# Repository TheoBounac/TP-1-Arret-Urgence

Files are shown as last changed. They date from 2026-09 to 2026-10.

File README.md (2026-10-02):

 <p align="center">
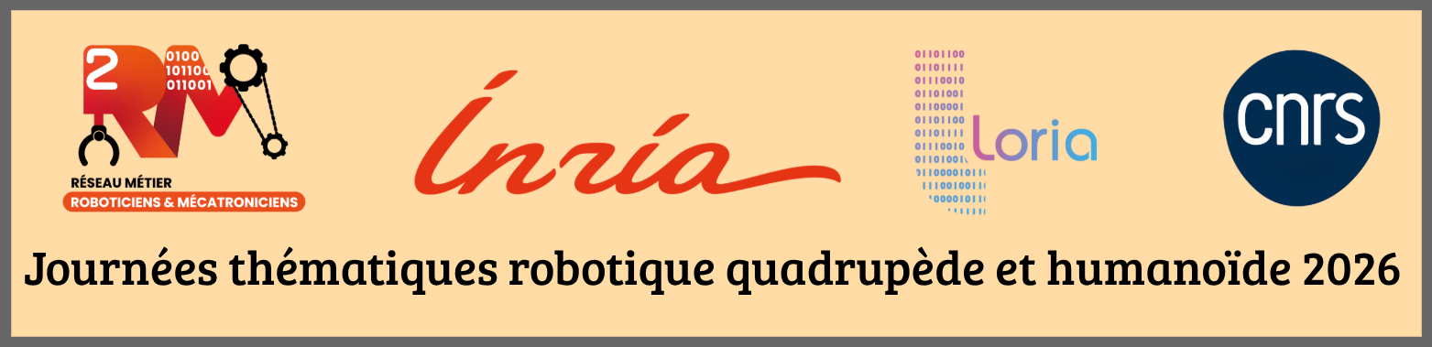
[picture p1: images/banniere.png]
  
  <br>
 </p>
 
 <div align="justify">
Le réseau métier des roboticiens et mécatroniciens du CNRS organise des journées thématiques sur les robots quadrupèdes et humanoïdes afin de favoriser le partage de connaissances et les retours d’expérience autour de ces robots. Cette journée est cofinancée par le réseau 2RM et INRIA. [12 et 13 octobre 2026] 
</div>

 ---
 
# TP1 — Arrêt d’urgence sans fil pour robots Unitree Go2/G1

 <p align="center">
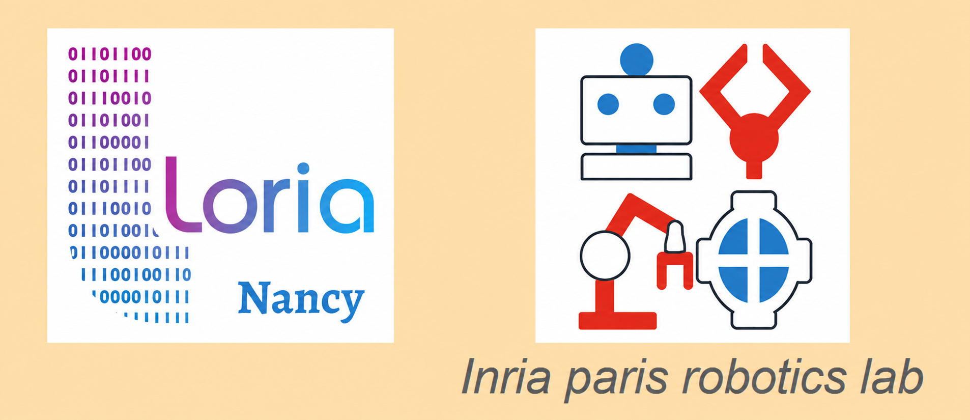
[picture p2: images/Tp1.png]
  
  <br>
 </p>

Ce TP est le premier TP des journées thématiques *robotique quadrupède et humanoïde 2026*. Cet arrêt d’urgence se base sur le travail réalisé par le laboratoire Inria Paris, équipe Willow: [https://github.com/inria-paris-robotics-lab/wireless-e-stop/tree/master](https://github.com/inria-paris-robotics-lab/wireless-e-stop/tree/master).

Ce TP a pour objectif de comprendre, assembler et tester un prototype d’arrêt d’urgence sans fil pour robots Unitree Go2 et G1.

## 📑 Sommaire

1. [Principe de fonctionnement du système](#principe)
2. [Matériel nécessaire](#composants)
3. [Montage de l'Emetteur](#transmetteur)
4. [Montage du Récepteur](#recepteurvrai)
5. [Fonctionnement logique](#logique)
6. [Test avec une LED](#test-led)
7. [Test sur le robot](#test-robot)

---

## 1. Principe de fonctionnement du système

 <div align="justify">
Sur la carte mère des robots Unitree Go2 et G1, deux broches portent le nom `STOP`. Lorsque ces deux broches sont reliées électriquement en circuit fermé, le robot coupe l’alimentation des moteurs et passe en état d’arrêt d’urgence, généralement signalé par des LEDs rouges.
</div>

 <p align="center">
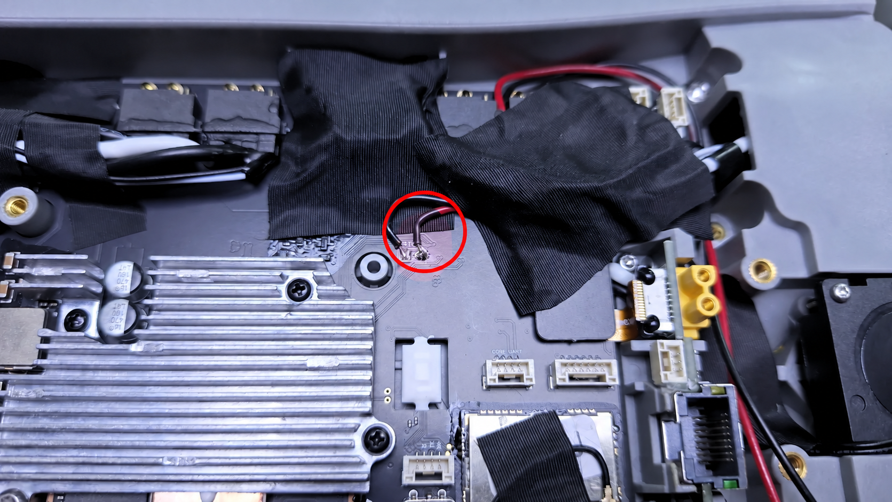
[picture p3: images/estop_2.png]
  
  <br>
  <em>Pin Stop sur la carte mère du Go2</em>
 </p>

Le système proposé repose sur deux groupes de composants :

- un **émetteur** côté opérateur 
- un **récepteur** côté robot.

 <div align="justify">
L’émetteur reste à proximité de l’opérateur. Lorsque l’opérateur appuie sur le bouton d’arrêt d’urgence, l'information est envoyée par radiofréquence au récepteur.
Le récepteur est accroché au robot et relié aux deux broches `STOP` de la carte mère par un relais, qui ferme le circuit en cas d'arrêt d'urgence qui coupe alors l'alimentation des moteurs du robot.
</div>

Schéma global :

 <p align="center">
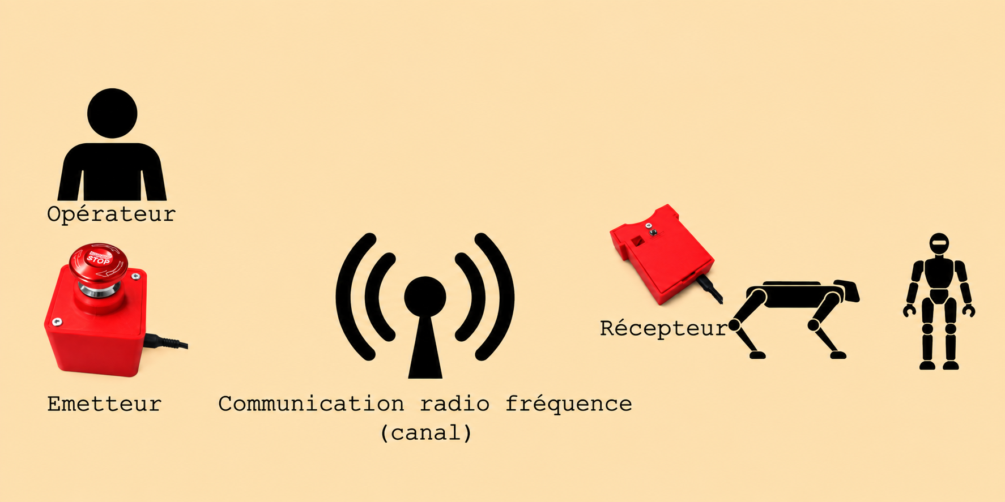
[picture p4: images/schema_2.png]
  
  <br>
 </p>

---

## 2. Matériel nécessaire

 <p align="center">
 <kbd>
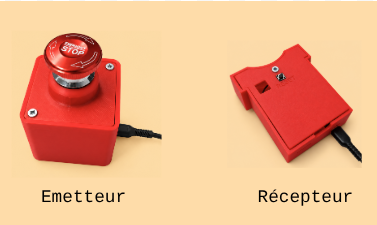
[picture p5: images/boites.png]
  
</kbd>
</p>
Tout le matériel est fourni le jour du TP.

### Emetteur
 <p align="center">
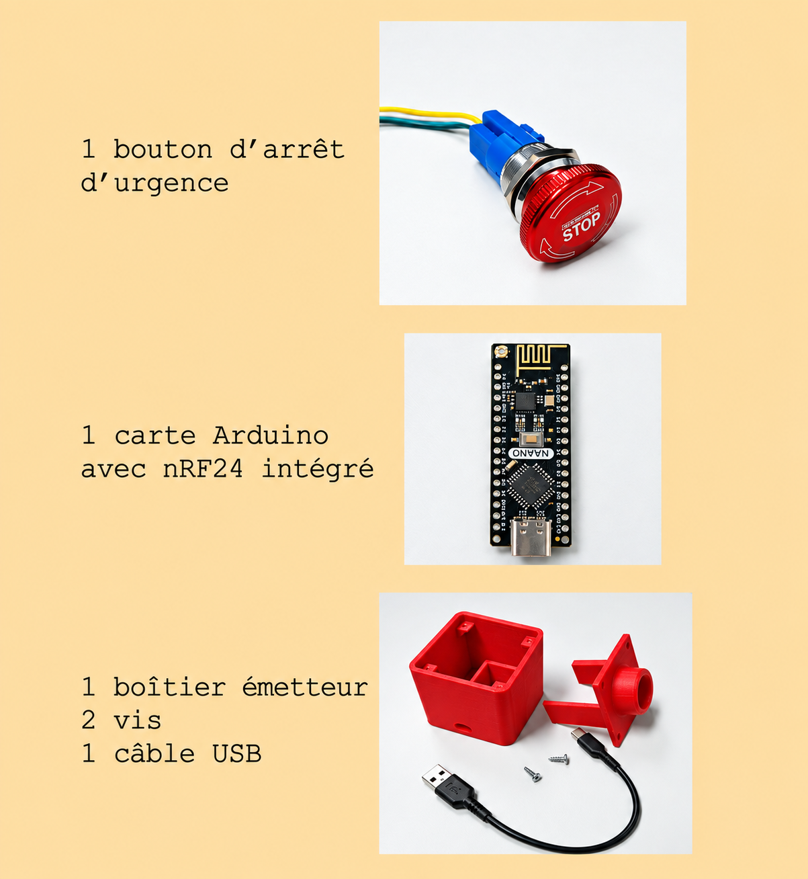
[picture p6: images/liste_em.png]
  
  <br>
 </p>

 ### Récepteur
 <p align="center">
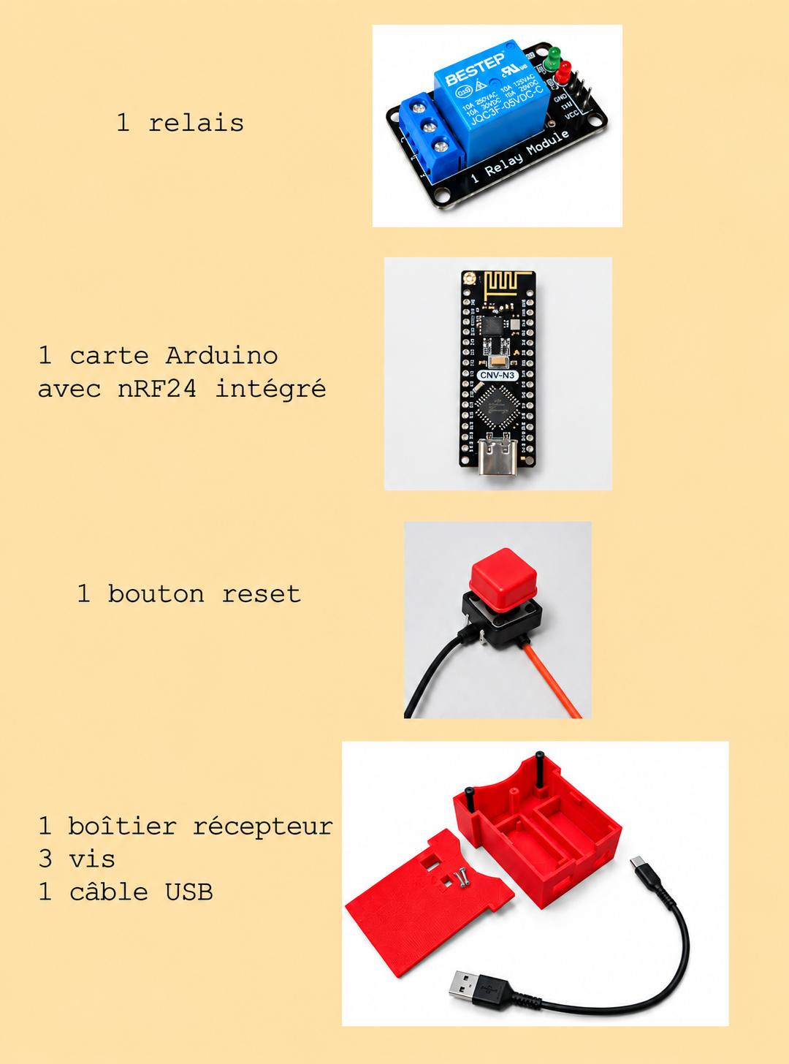
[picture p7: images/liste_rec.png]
  
  <br>
 </p>

---

## 3. Montage de l'Emetteur

<table align="center">
  <tr>
    <th>Carte Arduino</th>
  </tr>
  <tr>
    <td align="center">
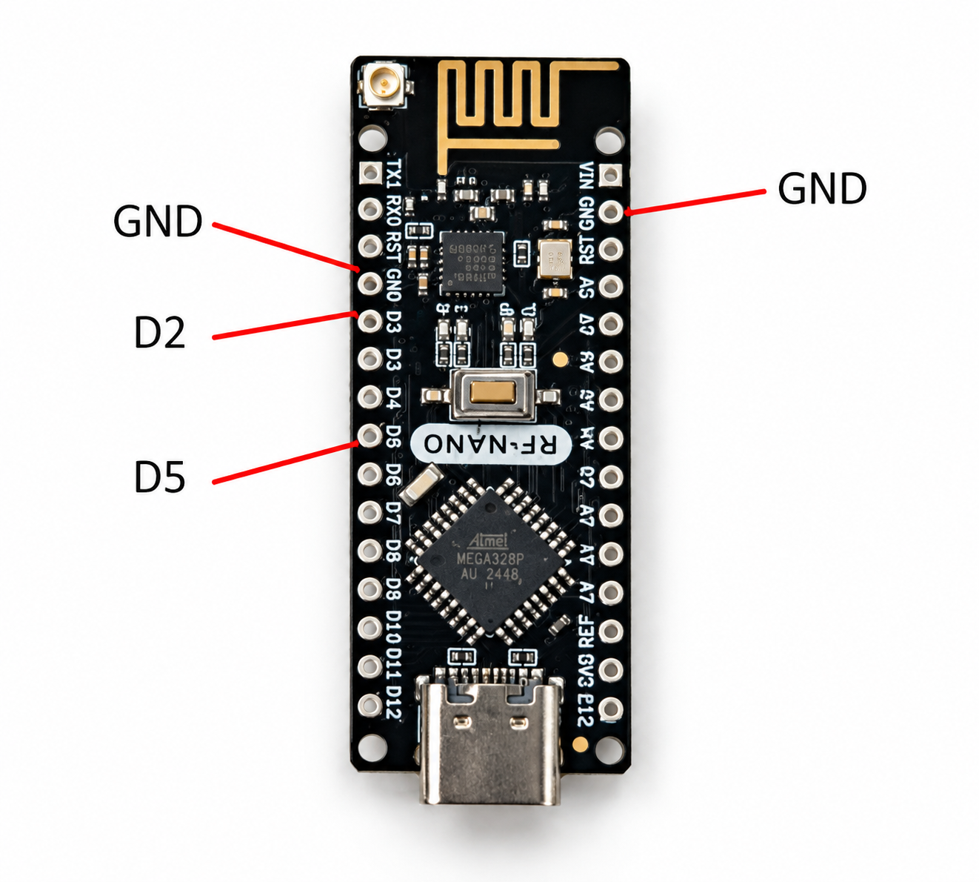
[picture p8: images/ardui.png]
Carte Arduino
      
    </td>
  </tr>
</table>

<div align="center">
<table>
  <tr>
    <th>STOP button</th>
    <th>Carte Arduino</th>
    <td rowspan="3">
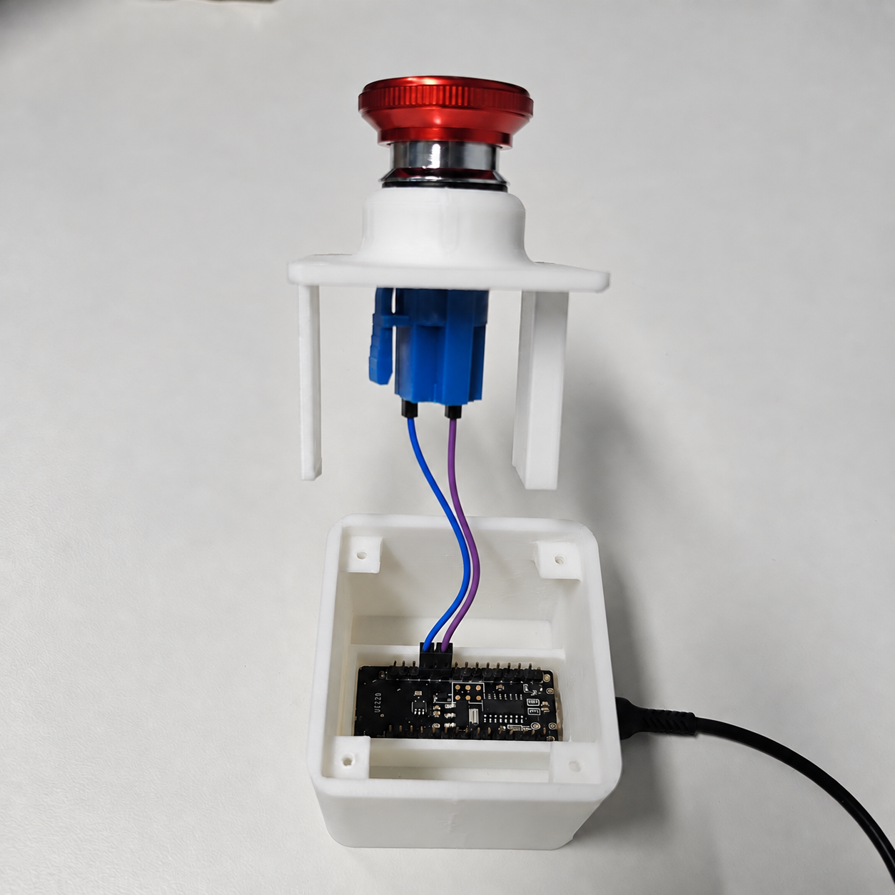
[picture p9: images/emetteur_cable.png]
Montage transmitter
      
    </td>
  </tr>

  <tr>
    <td>C / COM</td>
    <td>GND</td>
  </tr>

  <tr>
    <td>NC</td>
    <td>D2</td>
  </tr>
</table>
</div>
 
---

## 4. Montage du Récepteur

### Relais

<table align="center">
  <tr>
    <th>Relais</th>
    <th>Carte Arduino</th>
    <td rowspan="4">
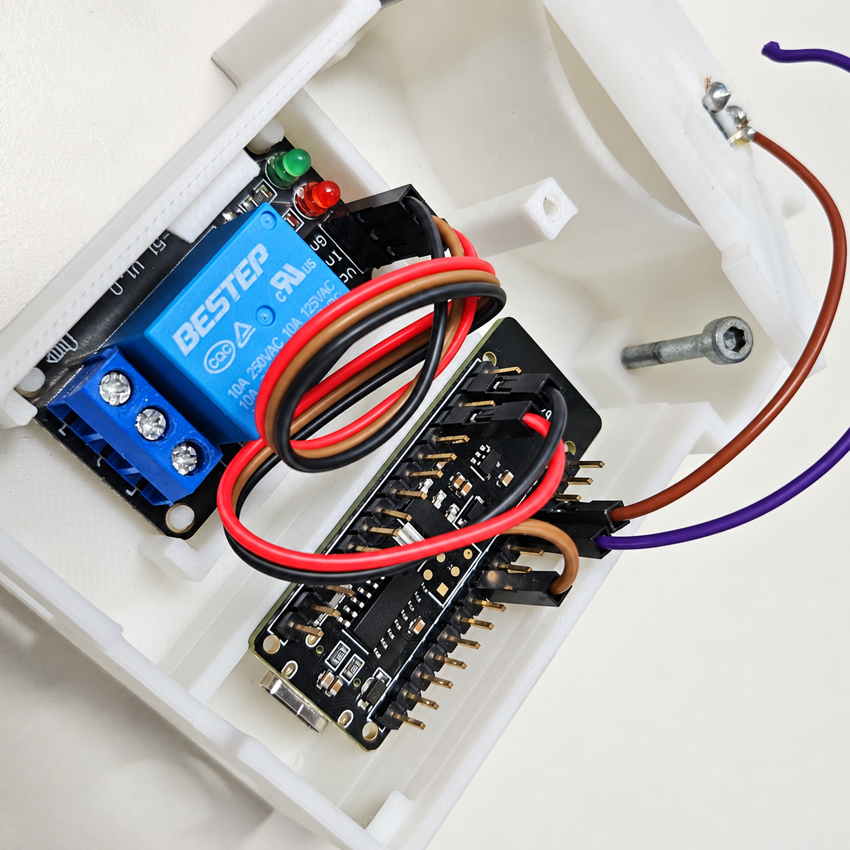
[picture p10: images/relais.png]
Montage relais
      
    </td>
  </tr>
  <tr>
    <td>VCC</td>
    <td>5V</td>
  </tr>
  <tr>
    <td>IN1</td>
    <td>D5</td>
  </tr>
  <tr>
    <td>GND</td>
    <td>GND</td>
  </tr>
</table>

### Bouton reset

<table align="center">
  <tr>
    <th>Reset button</th>
    <th>Carte Arduino</th>
    <td rowspan="3">
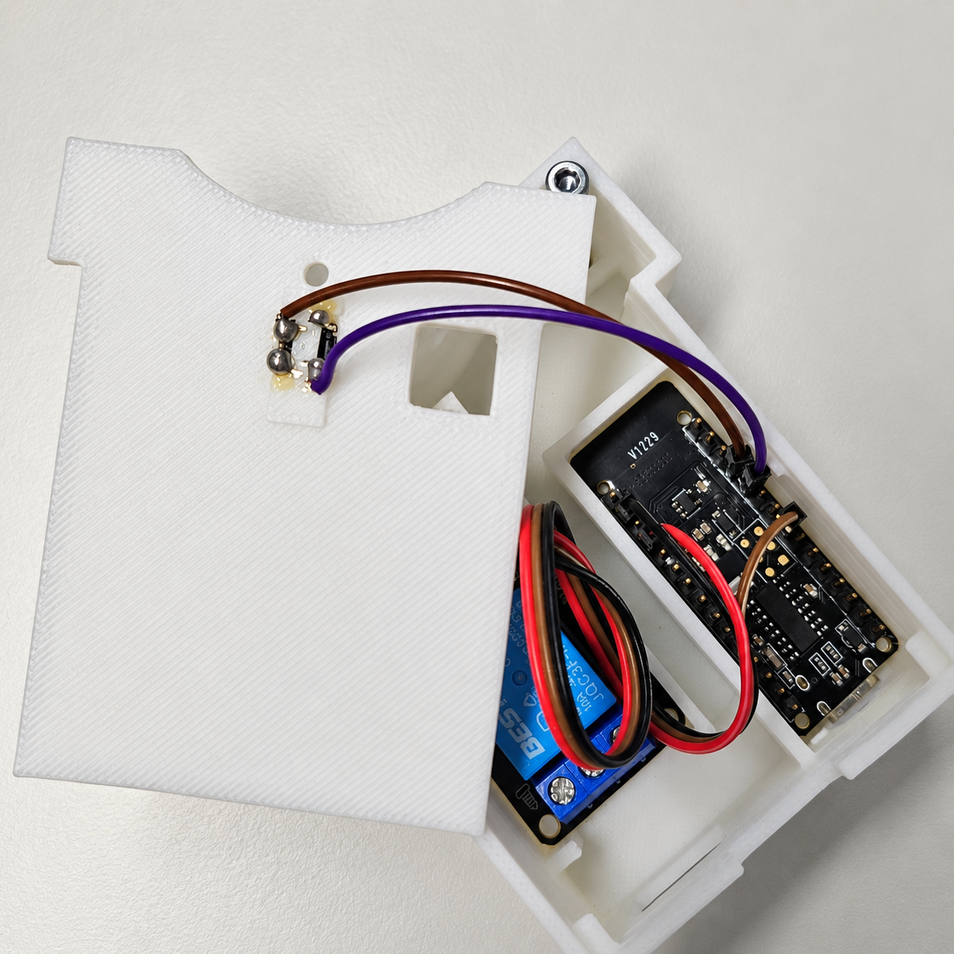
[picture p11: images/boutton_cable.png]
Montage bouton reset
      
    </td>
  </tr>
  <tr>
    <td>Pin 1</td>
    <td>D2</td>
  </tr>
  <tr>
    <td>Pin 2</td>
    <td>GND</td>
  </tr>
</table>

---
  
## 5. Fonctionnement logique

### Emetteur — `emetteur.ino`

L'émetteur :

- lit l’état du bouton d’arrêt d’urgence 
- convertit cet état en booléen 
- envoie ce booléen par radio toutes les 100 ms

### Récepteur — `recepteur.ino`

Le récepteur :

- écoute les messages radio envoyés par l'émetteur 
- utilise un algorithme de type **leaky bucket** pour détecter une perte de communication 
- commande le relais connecté aux broches `STOP` du robot

 ### Le relais ferme le circuit `STOP` dans les cas suivants :

- CAS 1: un message `TRUE` est reçu de l'émetteur 
- CAS 2: aucun message n’est reçu pendant une certaine période 
- CAS 3: l’alimentation du récepteur est coupée. Car le relais est en **normalement fermé**, c’est-à-dire que si l’alimentation du récepteur est coupée, le relais revient naturellement dans l’état qui déclenche l’arrêt d’urgence.
  
 <p align="center">
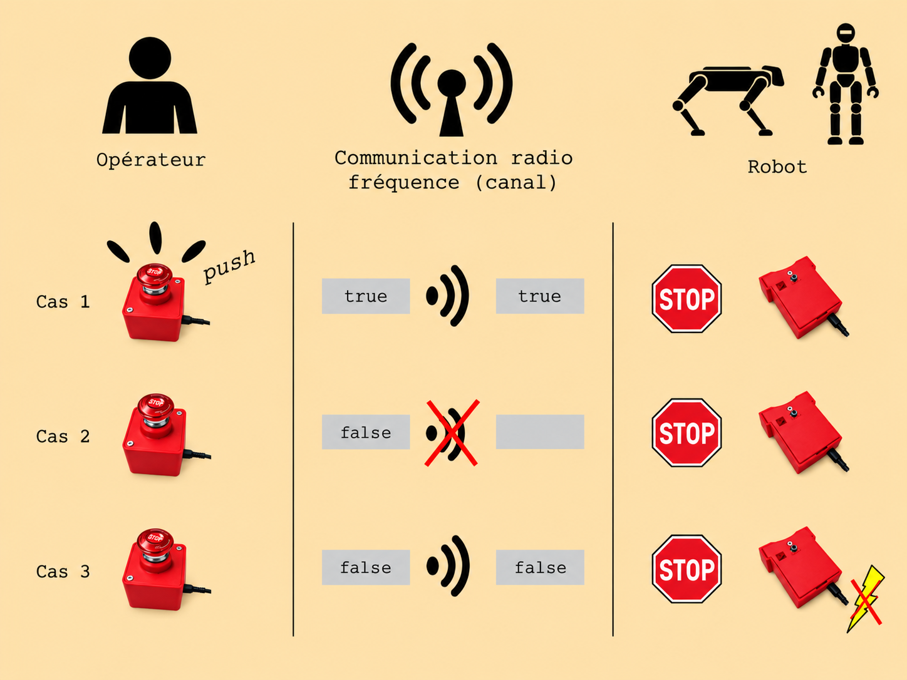
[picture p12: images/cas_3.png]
  
  <br>
 </p>

> ⚠️ **Attention**
>
> Lorsque le récepteur est alimenté, il place le relais en **circuit ouvert**, s'il n'est pas assez rapide pour effectuer cette action il peut au démarrage déclencher l'arrêt d'urgence.
> 
Après un arrêt d’urgence, si le receiver reste alimenté (par une batterie externe), le système doit être réarmé manuellement en maintenant le bouton reset pendant 3 secondes.

---

## 6. Test avec LED

Branchez la sortie du relais en circuit fermé avec la LED, comme indiqué sur la photo suivante :

 <p align="center">
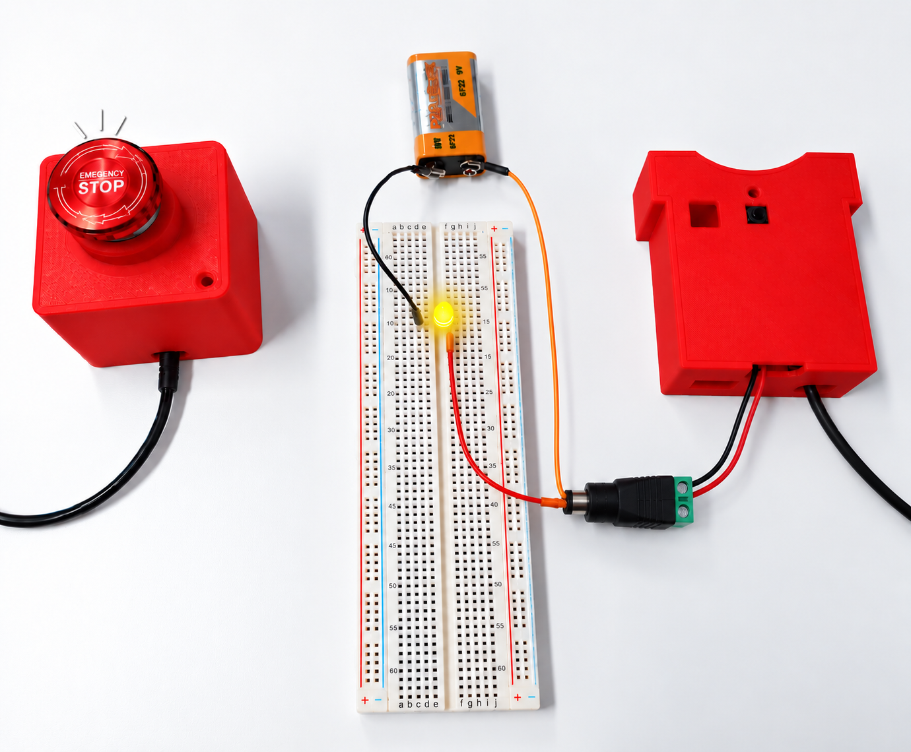
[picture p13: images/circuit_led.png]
  
  <br>
 </p>

Dans ce test :

```text
LED Jaune éteinte  → circuit ouvert → robot autorisé
LED Jaune allumée  → circuit fermé  → arrêt d’urgence activé, le robot est arrêté
```

Il est aussi possible de s’aider de la LED intégrée au module relais.

 <p align="center">
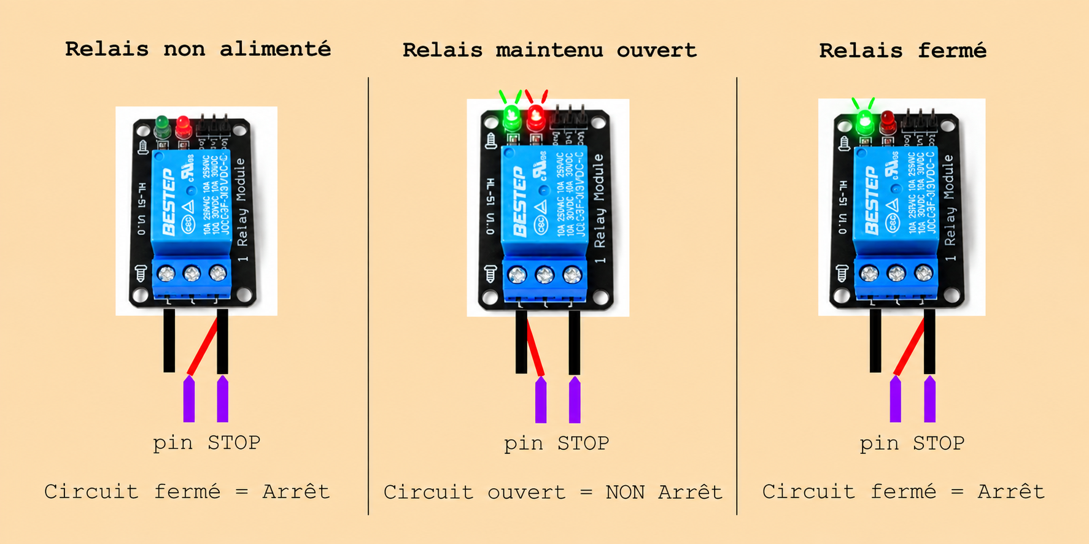
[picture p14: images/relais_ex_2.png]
  
  <br>
 </p>

---

## 7. Test sur robot

---

## 👥 Authors & Contributors

**Author:**  
Louise Manson, Timothee CARECCHIO, Laboratory **Inria Paris**

Théo Bounaceur, Laboratory **LORIA** CNRS

🧬 Field: Unitree robots · Emergency STOP 

📫 Contact: theo.bounaceur@loria.fr & louise.manson@inria.fr & timothee.carecchio@inria.fr

**Supervisors / Advisors:**  
- Pierre-guillaume Raverdy, Ingénieur robotique, Inria Paris
- Adrien Guenard, Ingénieur robotique, Loria

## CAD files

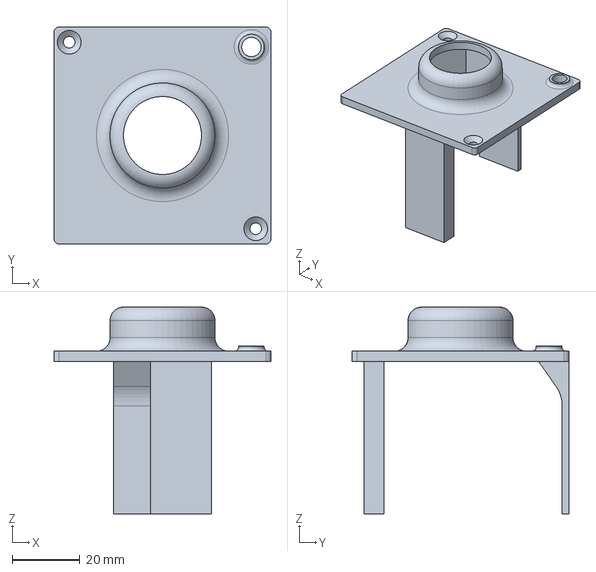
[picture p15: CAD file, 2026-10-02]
hardware/CAD/TransmitterTop_V2.FCStd
64.0 x 64.0 x 61.0 mm

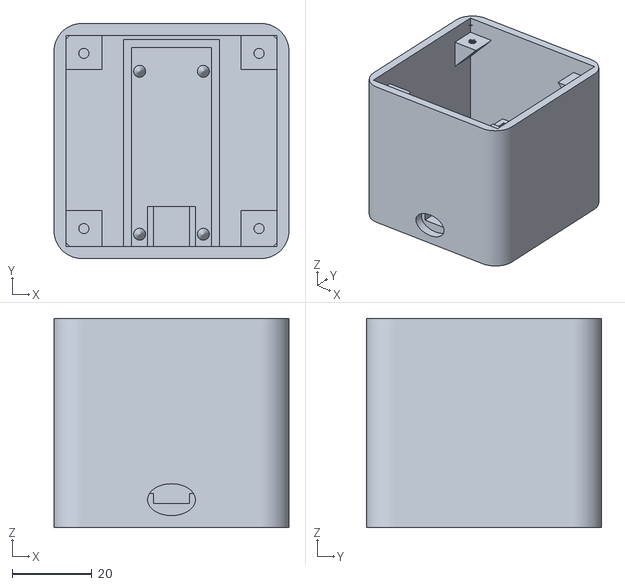
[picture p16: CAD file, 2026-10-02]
hardware/CAD/Transmitter-Corps.stl
59.0 x 59.0 x 52.5

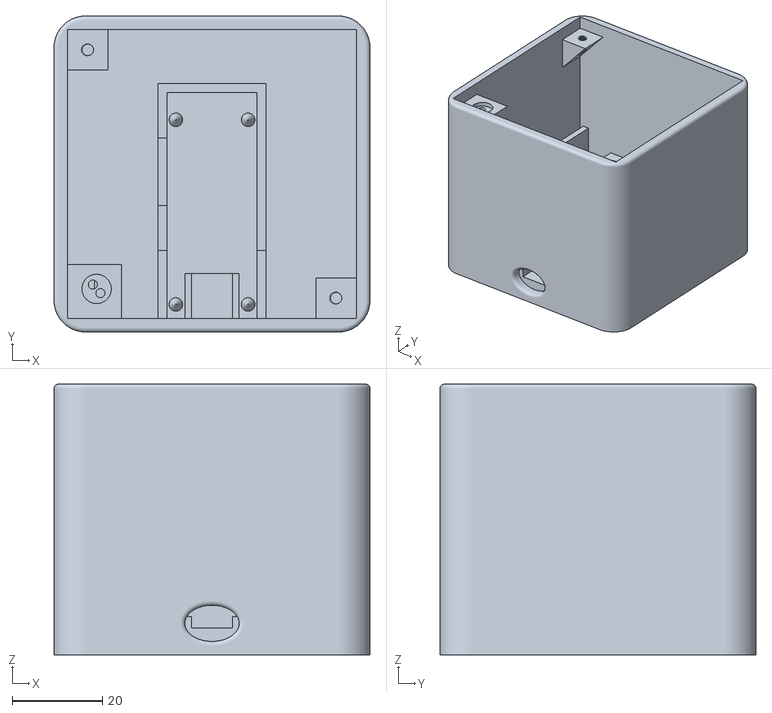
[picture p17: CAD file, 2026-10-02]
hardware/CAD/Transmitter_V4-Body.stl
70.0 x 70.0 x 60.0

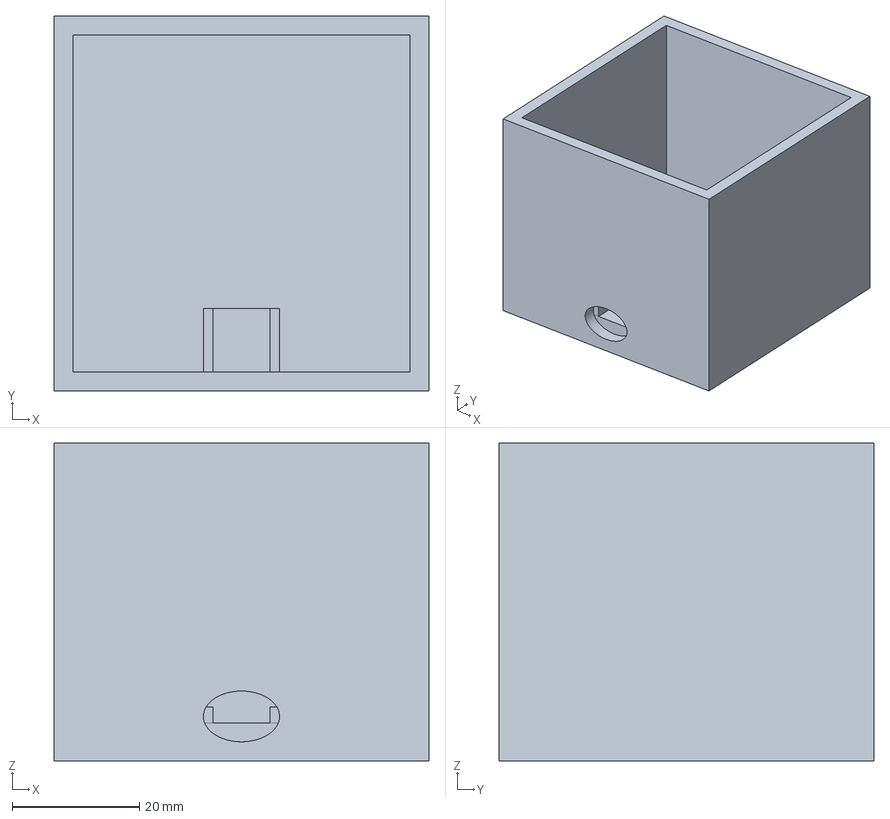
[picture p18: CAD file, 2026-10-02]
hardware/CAD/Transmitter.FCStd
59.0 x 59.0 x 50.0 mm

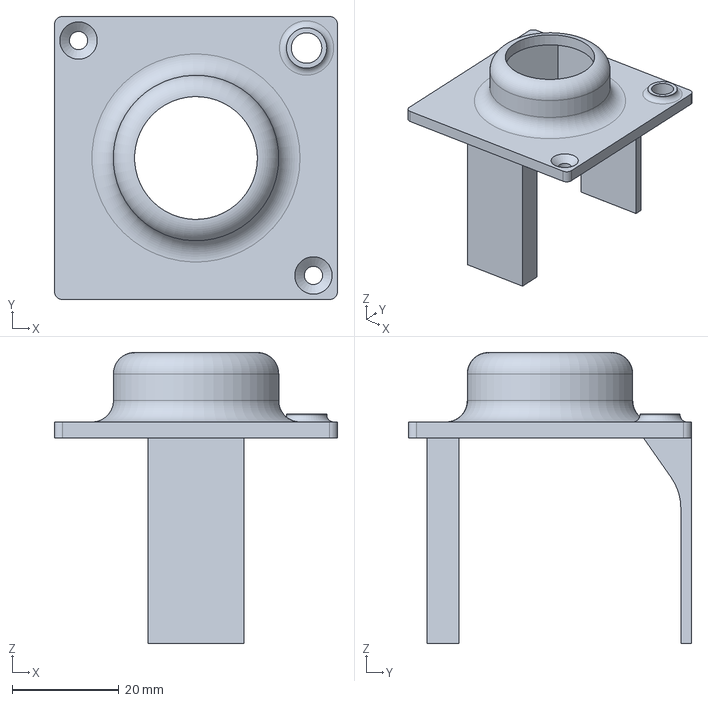
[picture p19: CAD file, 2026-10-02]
hardware/CAD/TransmitterTop.FCStd
53.0 x 53.0 x 54.5 mm

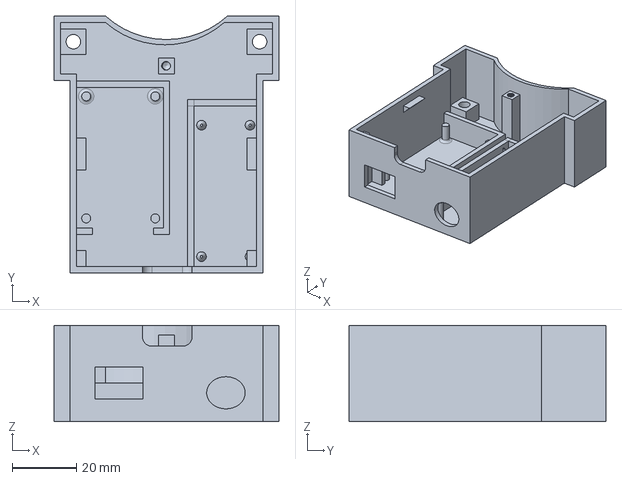
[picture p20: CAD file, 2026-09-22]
hardware/CAD/Receiver.FCStd
70.0 x 80.0 x 30.0 mm

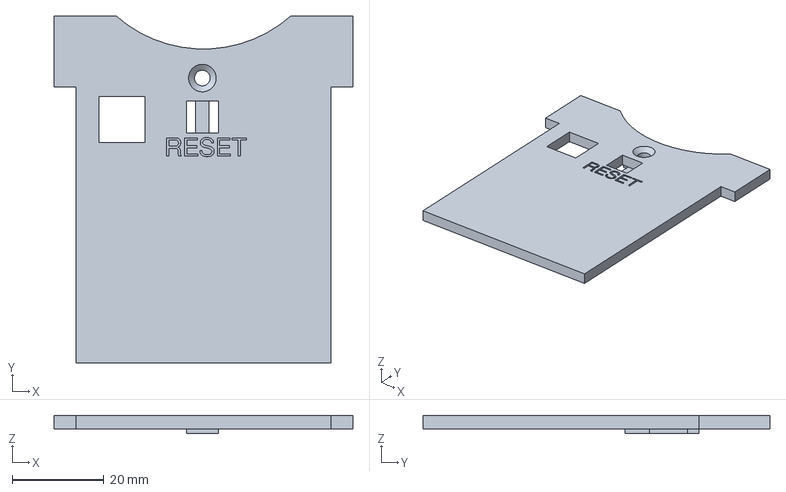
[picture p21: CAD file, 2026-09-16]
hardware/CAD/ReceiverTop.FCStd
65.0 x 75.5 x 4.00 mm

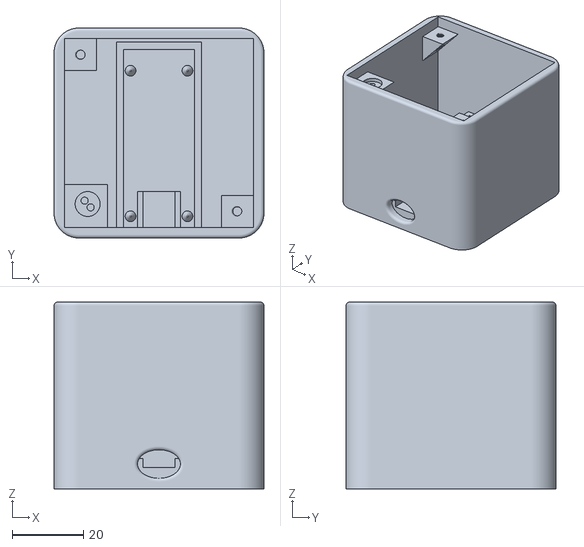
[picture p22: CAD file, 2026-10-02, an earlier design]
hardware/CAD/Transmitter_V2-Body.stl
59.0 x 59.0 x 52.5

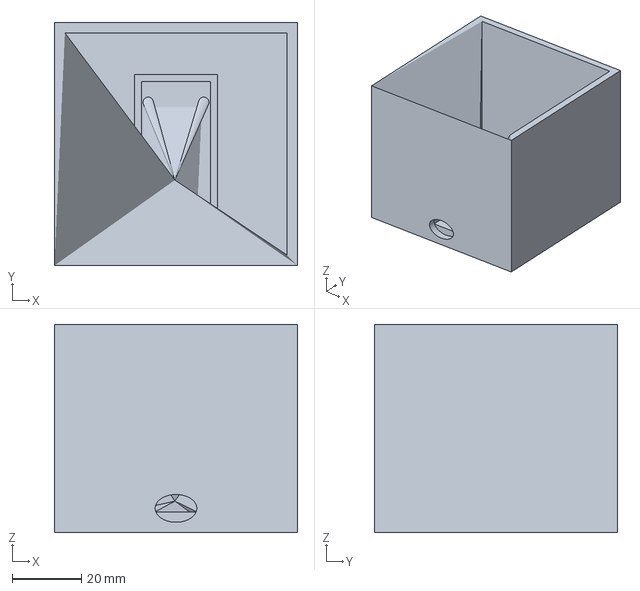
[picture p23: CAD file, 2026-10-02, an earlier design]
hardware/CAD/Transmitter_V3.FCStd
70.0 x 70.0 x 60.0 mm

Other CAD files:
hardware/CAD/Transmitter (copy).FCStd
hardware/CAD/Transmitter_V4.FCStd
hardware/CAD/TransmitterTop-Body.stl
hardware/CAD/TransmitterTop_V2-Body.stl
hardware/CAD/Transmitter_V2.FCStd

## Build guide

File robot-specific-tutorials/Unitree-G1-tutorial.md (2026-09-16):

Wiring tutorial on Unitree G1
===
> [!IMPORTANT]
> Remove the battery from the robot before opening it.

Lay the robot on its front so that you can access the screws in the back.   
Unscrew the two screws of the handle.   

<div align="center">
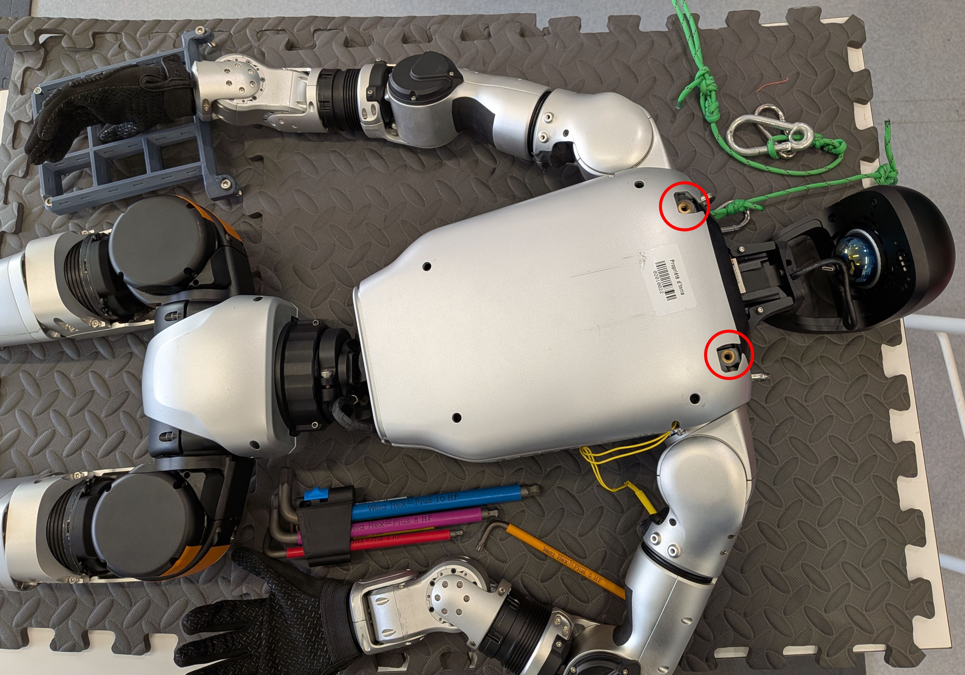
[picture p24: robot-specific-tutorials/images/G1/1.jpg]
Robot on its back with the 2 screws to remove marked in red

</div>
<br>

With a plastic card pop open the plastic outer shell. The clips that needs to be pushed are marked in red in the following pictures, be careful to also remove the one on top of the shoulder.   

<table>
    <td>
        <div align="center">
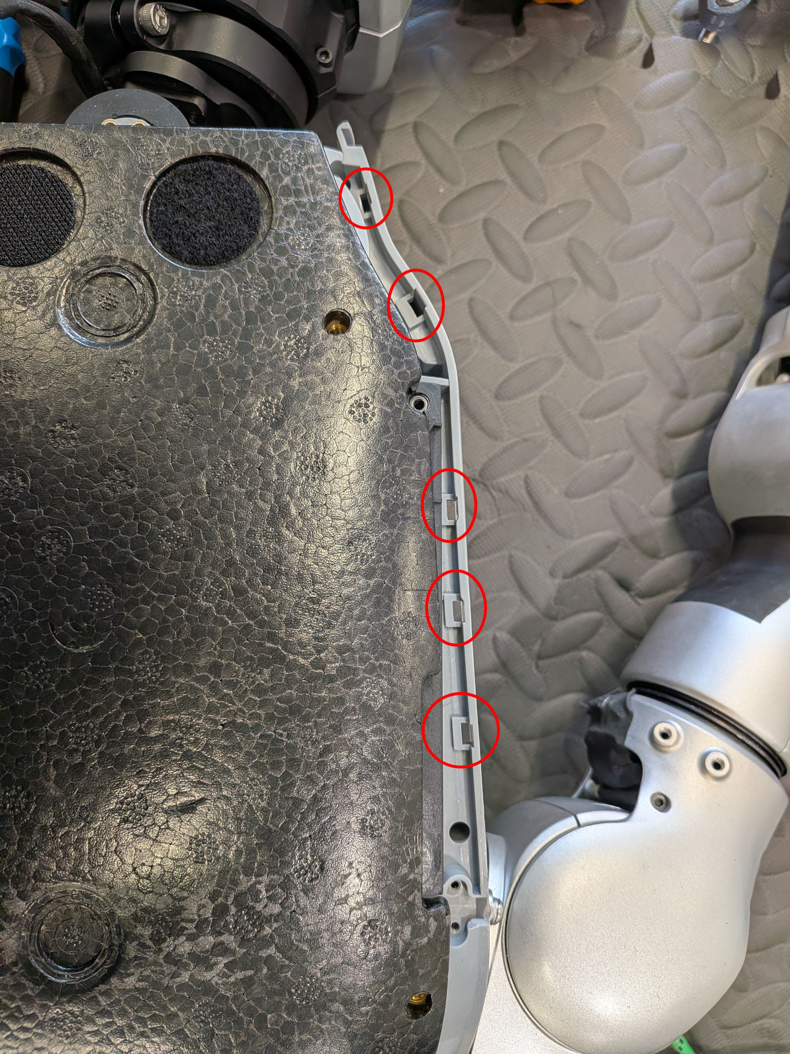
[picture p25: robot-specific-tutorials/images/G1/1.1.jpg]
            
        </div>
    </td>
        <td>
        <div align="center">
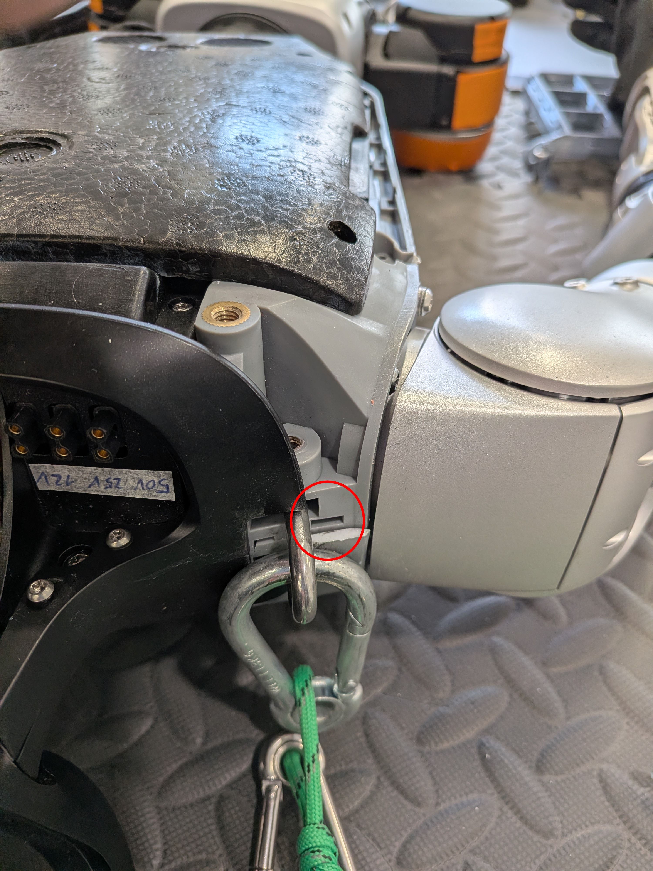
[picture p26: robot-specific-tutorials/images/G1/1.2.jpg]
            
        </div>
    </td>
</table>
<br>

Next to remove the polyester pannel unscrew the 4 screws marked in red and carefully pull. The bottom part of the pannel (where there are two velcro pads) is double taped, use a plastic card to carefuly unstick it and pull off the pannel entirely.  

<div align="center">
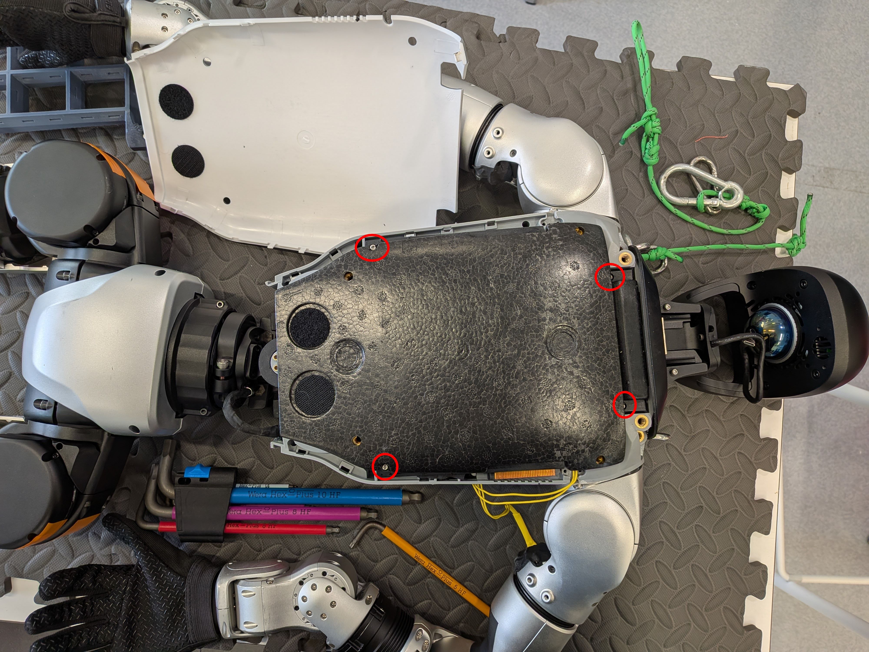
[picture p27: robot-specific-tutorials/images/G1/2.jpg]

</div>
<br>

The emergency stop plug is dead-center (in red).   
<div align="center">
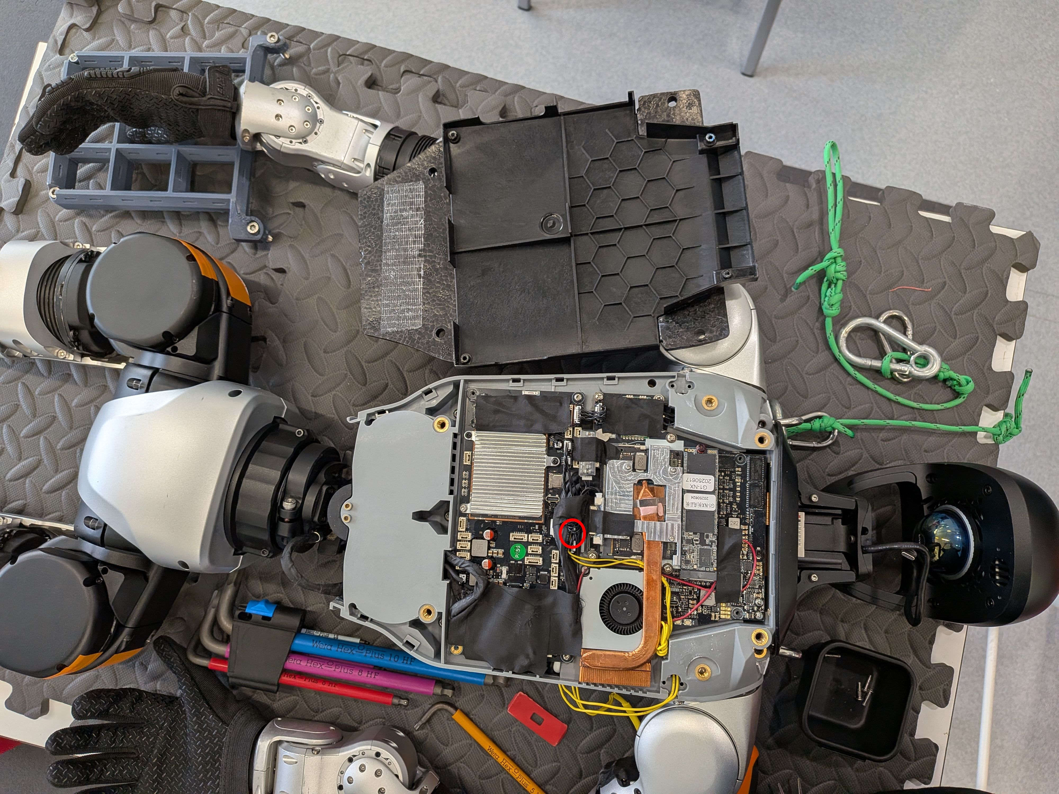
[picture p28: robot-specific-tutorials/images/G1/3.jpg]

</div>
<br>

You will need to wire 2 wires to a GH 1.25 mm 2 pin male connector.  Keep the other end of the wires unsoldered so that you can thread them under the caloduc and through the vent to the outside the robot.
<table>
    <td>
        <div align="center">
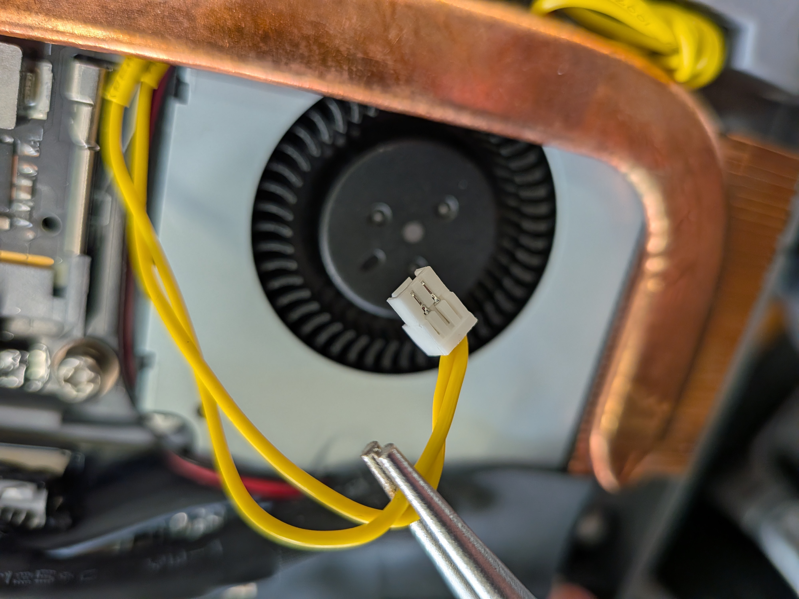
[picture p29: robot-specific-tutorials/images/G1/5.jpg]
            
        </div>
    </td>
        <td>
        <div align="center">
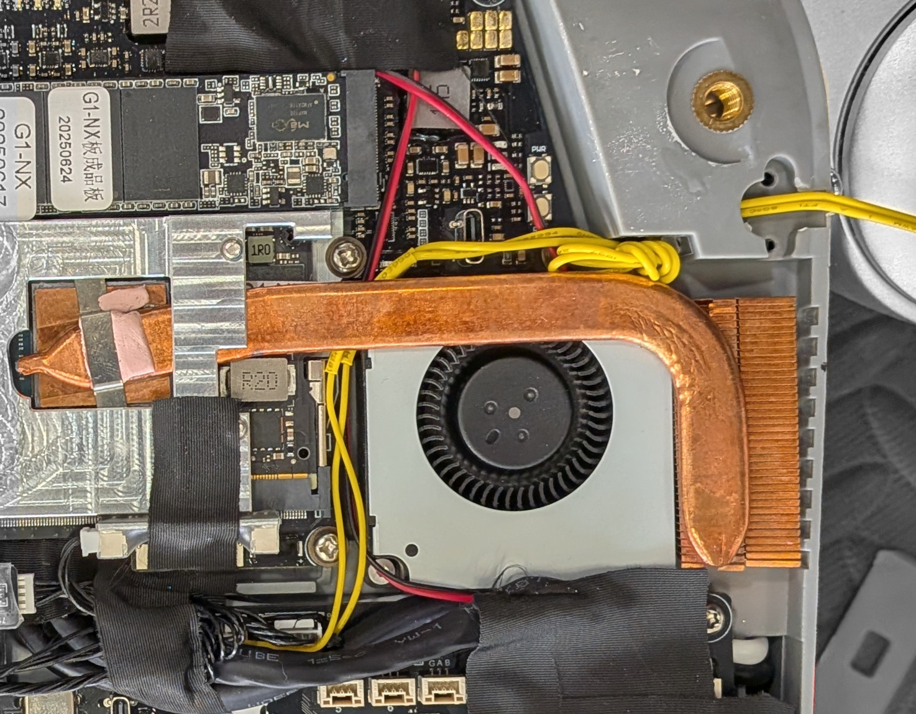
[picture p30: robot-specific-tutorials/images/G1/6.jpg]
            
        </div>
    </td>
</table>
<br>

You can connect the other end of the wire (the part that will be outside of the robot) directly to the receiver module or to any connector of your liking.  
We use a female 5.5 x 2.1mm Power Jack connector plugged to a male connector of the same type soldered to the receiver :
<div align="center">
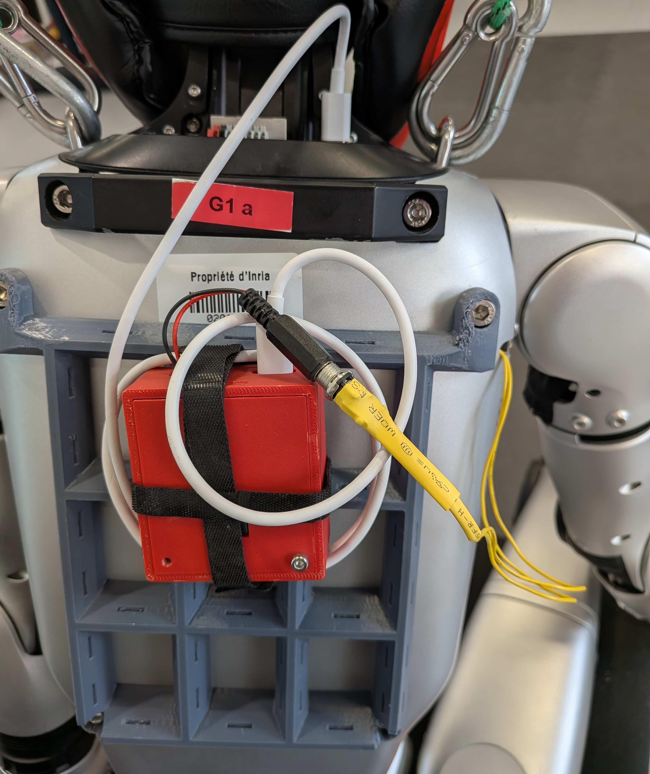
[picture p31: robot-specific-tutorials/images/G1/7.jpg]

</div>
<br>   

The "backpack" can be found in our [CAD-parts repository](https://github.com/inria-paris-robotics-lab/CAD-parts/).

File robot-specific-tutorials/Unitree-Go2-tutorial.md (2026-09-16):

Wiring tutorial on Unitree Go2
===
> [!IMPORTANT]
> Remove the battery from the robot before opening it.

Unscrew the two screws of the handle.   

<div align="center">
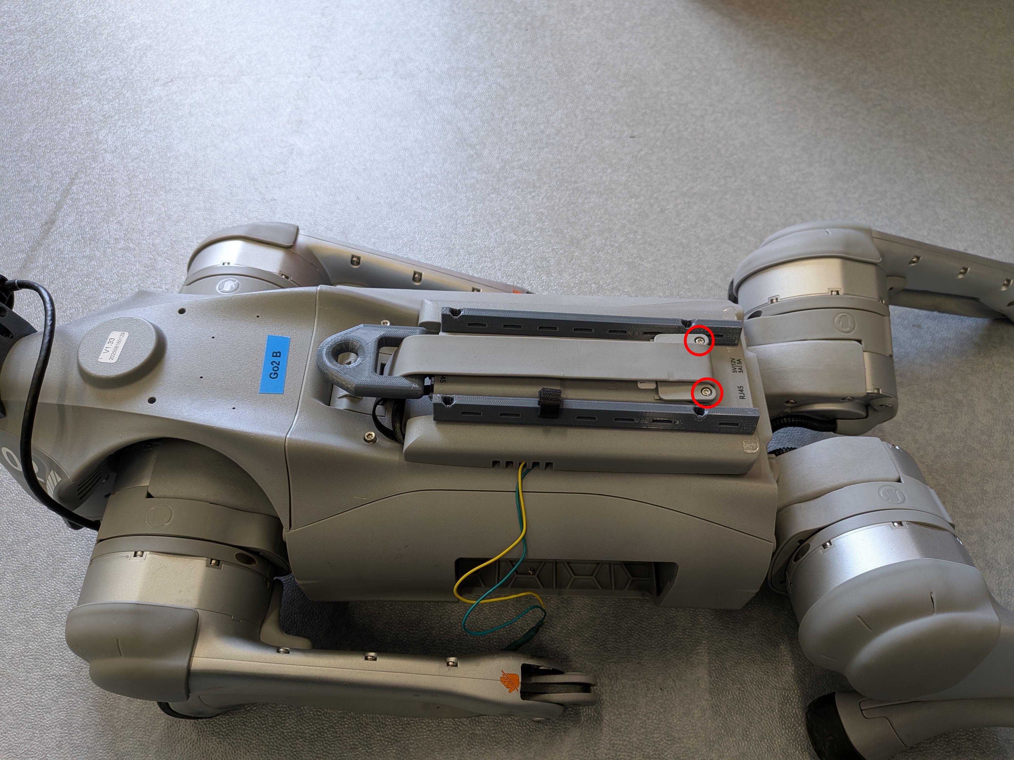
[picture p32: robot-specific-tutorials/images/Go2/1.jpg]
The 2 screws of the handle marked in red

</div>
<br>

Remove the 4 screws that holds the Jetson.

<div align="center">
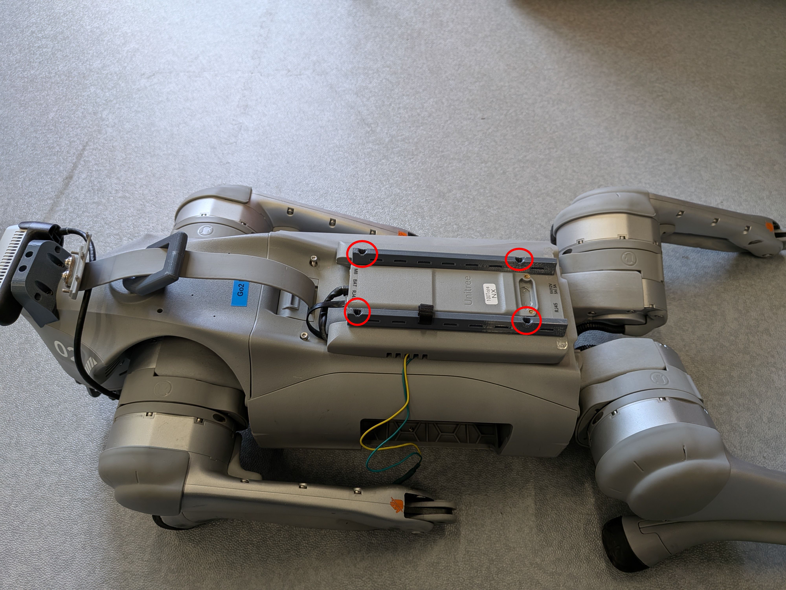
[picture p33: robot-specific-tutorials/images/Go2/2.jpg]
The 4 screws of the jetson marked in red

</div>
<br>

Next, unplug the power and ethernet wire connecting the robot to the Jetson and put the Jetson aside.   
<div align="center">
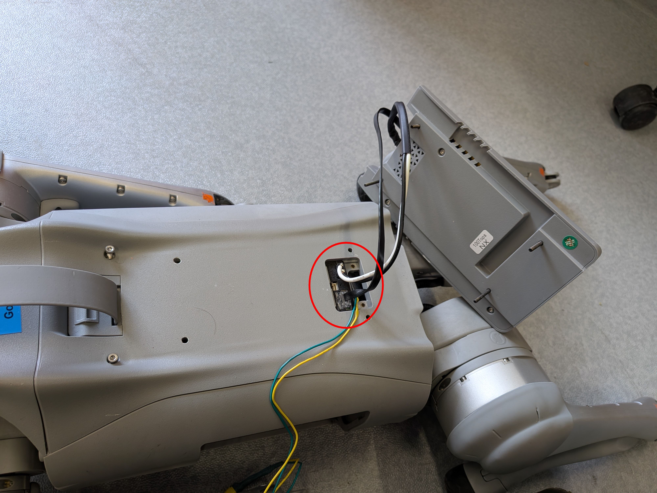
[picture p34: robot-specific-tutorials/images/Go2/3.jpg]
The wires to unplug marked in red

</div>
<br>

To remove the top plastic shell of the robot and access the mother board, remove 4 screws: two on the top and two on the back, near the legs actuators.    
<table>
    <td>
        <div align="center">
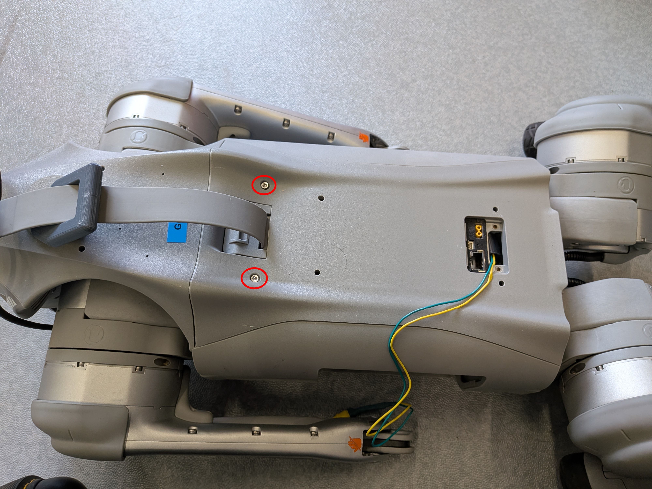
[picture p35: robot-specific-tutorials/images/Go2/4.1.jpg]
Localisation of the top screws
            
        </div>
    </td>
        <td>
        <div align="center">
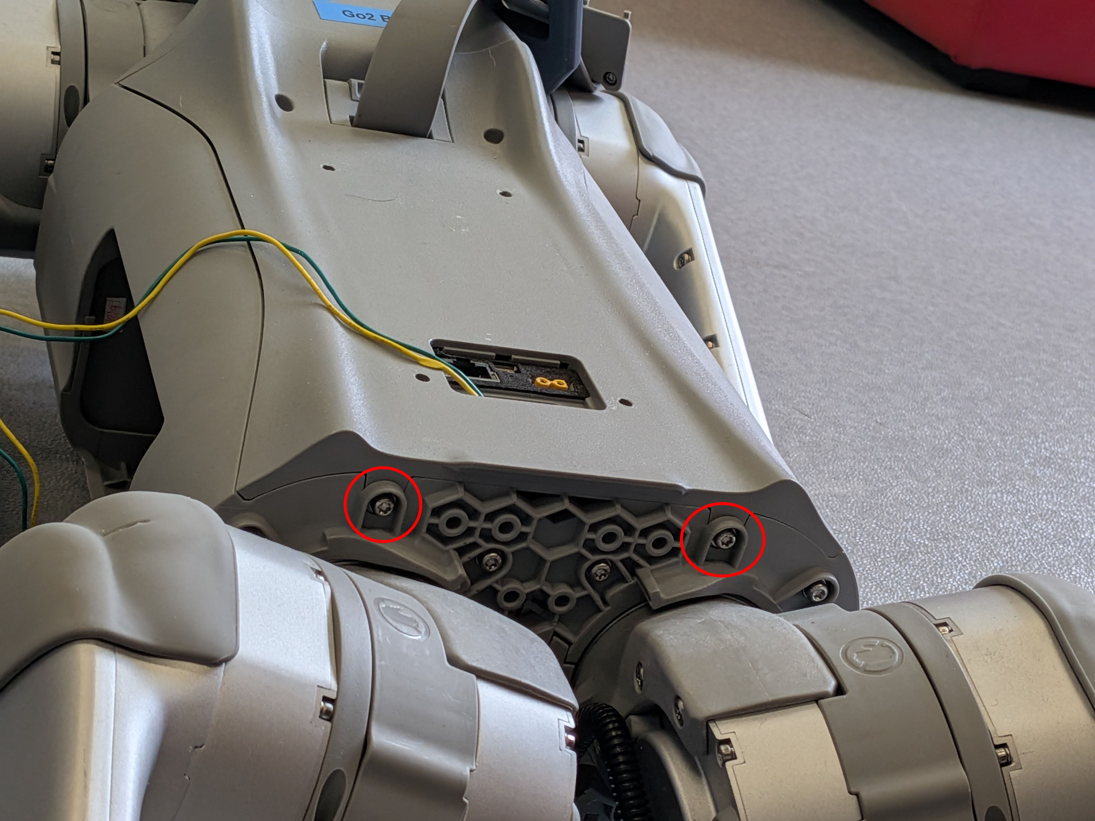
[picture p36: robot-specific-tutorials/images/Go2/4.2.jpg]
Localisation of the back screws
            
        </div>
    </td>
</table>
<br>

Remove the cover.

<div align="center">
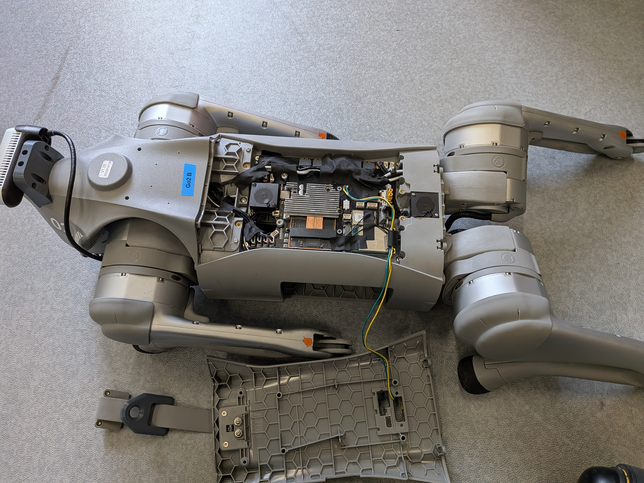
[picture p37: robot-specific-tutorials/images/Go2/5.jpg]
The robot with the cover opened

</div>
<br>

Solder two wires directly to the mother board on the emegency pads (in red). And thread them through the hole in the top pannel that is used for the ethernet and the power for the Jetson.   

<div align="center">
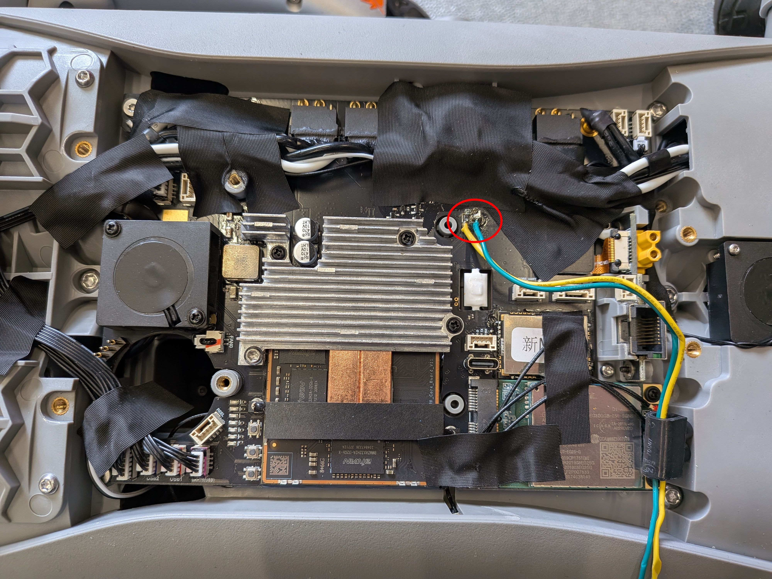
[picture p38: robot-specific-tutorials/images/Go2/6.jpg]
The robot motherboard

</div>
<br>

You can connect the other end of the wire (the part that will be outside of the robot) directly to the receiver module or to any connector of your liking.  
We use a female 5.5 x 2.1mm Power Jack connector plugged to a male connector of the same type soldered to the receiver.

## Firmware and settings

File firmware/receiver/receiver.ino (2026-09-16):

#include <EEPROM.h>
#include <RF24.h>
#include <SPI.h>
#include <nRF24L01.h>

#define CE_PIN 10
#define CSN_PIN 9
#define RESET_BUTTON_PIN 2
#define RELAY_PIN 5

// IMPORTANT : logique relais pour branchement robot sur COM + NC
// RELAY_RUN  = état qui OUVRE COM-NC  -> robot autorisé
// RELAY_STOP = état qui FERME COM-NC  -> arrêt urgence robot
#define RELAY_RUN  LOW
#define RELAY_STOP HIGH

int EEPROM_ADDRESS = 0;
int ChannelNumber = 0;

RF24 radio(CE_PIN, CSN_PIN);

const byte address[6] = "1234";

int state = 0; // 0: ARMED, 1: SECURED
int relay_state = RELAY_RUN;
bool msg = true;

bool radioOK = false;

// Startup grace period
const unsigned long STARTUP_GRACE_TIME = 3000;
unsigned long startupTime = 0;
bool startupGraceActive = true;

// Reset button parameters
bool buttonPressed = false;
unsigned long buttonPressTime = 0;
const unsigned long RESET_HOLD_TIME = 3000;

// Leaky bucket parameters
const int BUCKET_CAPACITY = 6;
int bucketLevel = BUCKET_CAPACITY;
unsigned long lastLeakTime = 0;
const long LEAK_INTERVAL = 150;

// Debug parameters
unsigned long lastDebugPrint = 0;
const unsigned long DEBUG_INTERVAL = 500;

void setRelayRun() {
  relay_state = RELAY_RUN;
  digitalWrite(RELAY_PIN, relay_state);
}

void setRelayStop() {
  relay_state = RELAY_STOP;
  digitalWrite(RELAY_PIN, relay_state);
}

void triggerAlarm(const char* reason) {
  if (state == 0) {
    state = 1;
    setRelayStop();

    Serial.print("Alarm triggered: ");
    Serial.println(reason);
  } else {
    Serial.print("Already secured, alarm ignored: ");
    Serial.println(reason);
  }
}

void printDebugStatus() {
  if (millis() - lastDebugPrint >= DEBUG_INTERVAL) {
    lastDebugPrint = millis();

    Serial.print("D2 reset=");
    Serial.print(digitalRead(RESET_BUTTON_PIN) == LOW ? "APPUYE" : "RELACHE");

    Serial.print(" | D5 relais=");
    Serial.print(digitalRead(RELAY_PIN) == HIGH ? "HIGH" : "LOW");

    Serial.print(" | state=");
    Serial.print(state == 0 ? "ARMED" : "SECURED");

    Serial.print(" | bucket=");
    Serial.print(bucketLevel);

    Serial.print(" | last msg=");
    Serial.print(msg ? "TRUE" : "FALSE");

    Serial.print(" | radio=");
    Serial.print(radioOK ? "OK" : "NOT OK");

    Serial.print(" | startup=");
    Serial.println(startupGraceActive ? "GRACE" : "NORMAL");
  }
}

void setup() {
  // Très important : commander le relais immédiatement.
  // Rien avant ça.
  pinMode(RELAY_PIN, OUTPUT);
  setRelayRun();

  pinMode(RESET_BUTTON_PIN, INPUT_PULLUP);

  startupTime = millis();
  lastLeakTime = millis();

  Serial.begin(115200);
  Serial.println("Receiver debug start");
  Serial.println("Relay forced to RUN immediately");
  Serial.println("Startup grace period active for 3 seconds");

  EEPROM.get(EEPROM_ADDRESS, ChannelNumber);
  if (ChannelNumber < 0 || ChannelNumber > 125) {
    ChannelNumber = 108;
    EEPROM.put(EEPROM_ADDRESS, ChannelNumber);
  }

  Serial.print("EEPROM channel=");
  Serial.println(ChannelNumber);

  // Mode setup canal radio.
  // Le relais reste en RUN pendant ce mode.
  if (digitalRead(RESET_BUTTON_PIN) == LOW) {
    Serial.println("Mode Setup");
    Serial.println("Please enter the new Channel (0-125): ");

    while (!Serial.available()) {
      // On garde le relais ouvert pendant l'attente setup
      setRelayRun();
    }

    int newChannel = Serial.parseInt();

    while (!(newChannel >= 0 && newChannel <= 125)) {
      Serial.println("Invalid input. Please enter a valid channel (0-125): ");

      while (!Serial.available()) {
        setRelayRun();
      }

      newChannel = Serial.parseInt();
    }

    if (newChannel != ChannelNumber) {
      Serial.print("Default Channel set to: ");
      Serial.println(newChannel);
      EEPROM.put(EEPROM_ADDRESS, newChannel);
      ChannelNumber = newChannel;
    }

    Serial.println("Setup complete. Please release the button to continue.");

    while (digitalRead(RESET_BUTTON_PIN) == LOW) {
      setRelayRun();
      delay(100);
    }
  }

  Serial.println("Starting radio...");

  radioOK = radio.begin();

  if (!radioOK) {
    Serial.println("Radio non detectee au demarrage");
    Serial.println("Receiver will go to STOP after startup grace period");
  } else {
    radio.setPALevel(RF24_PA_MAX);
    radio.setPayloadSize(sizeof(msg));
    radio.setChannel(ChannelNumber);
    radio.setDataRate(RF24_1MBPS);
    radio.openReadingPipe(1, address);
    radio.startListening();

    Serial.println("Radio OK");
  }

  Serial.println("Receiver ready");
}

void loop() {
  printDebugStatus();

  uint8_t pipe;

  // Pendant les 3 premières secondes, on force le relais en RUN.
  if (startupGraceActive) {
    setRelayRun();

    if (millis() - startupTime >= STARTUP_GRACE_TIME) {
      startupGraceActive = false;
      Serial.println("Startup grace period finished");

      // Après les 3 secondes, si la radio n'est pas OK, arrêt immédiat.
      if (!radioOK) {
        triggerAlarm("radio not available after startup");
      }
    }

    return;
  }

  // Handle reset button when system is secured
  if (state == 1) {
    if (digitalRead(RESET_BUTTON_PIN) == LOW) {
      if (!buttonPressed) {
        buttonPressed = true;
        buttonPressTime = millis();
        Serial.println("Reset button pressed");
      } else {
        unsigned long heldTime = millis() - buttonPressTime;

        Serial.print("Reset held for ");
        Serial.print(heldTime);
        Serial.println(" ms");

        if (heldTime >= RESET_HOLD_TIME) {
          Serial.println("RESET VALIDATED -> back to ARMED");

          state = 0;
          setRelayRun();

          buttonPressed = false;
          bucketLevel = BUCKET_CAPACITY;
          lastLeakTime = millis();
        }
      }
    } else {
      if (buttonPressed) {
        Serial.println("Reset button released before 3s");
      }
      buttonPressed = false;
    }
  }

  // Si la radio n'est pas OK, arrêt.
  if (!radioOK) {
    if (state == 0) {
      triggerAlarm("radio not available");
    }
    return;
  }

  // Check for incoming radio data
  if (radio.available(&pipe)) {
    Serial.print("Radio message received on pipe ");
    Serial.println(pipe);

    bucketLevel = min(bucketLevel + 1, BUCKET_CAPACITY);
    lastLeakTime = millis();

    radio.read(&msg, sizeof(msg));

    Serial.print("msg=");
    Serial.println(msg ? "ALARM TRUE" : "ALARM FALSE");

    if (msg) {
      triggerAlarm("button alarm received");
    }
  } else {
    if (state == 0) {
      if (millis() - lastLeakTime > LEAK_INTERVAL) {
        bucketLevel = max(bucketLevel - 1, 0);
        lastLeakTime = millis();

        Serial.print("No radio data, bucket=");
        Serial.println(bucketLevel);
      }

      if (bucketLevel == 0) {
        triggerAlarm("signal loss");
      }
    }
  }
}

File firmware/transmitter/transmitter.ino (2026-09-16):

#include <EEPROM.h>
#include <RF24.h>
#include <SPI.h>
#include <nRF24L01.h>

#define CE_PIN 10
#define CSN_PIN 9
#define BUTTON_PIN 2

int EEPROM_ADDRESS = 0;
int ChannelNumber = 0;

int period = 100;

RF24 radio(CE_PIN, CSN_PIN);

const byte address[6] = "1234";

bool msg = false;

unsigned long packetCount = 0;
unsigned long lastDebugPrint = 0;
const unsigned long DEBUG_INTERVAL = 500;

void setup() {
  Serial.begin(115200);
  delay(1000);
  Serial.println("Transmitter debug start");

  pinMode(BUTTON_PIN, INPUT_PULLUP);

  EEPROM.get(EEPROM_ADDRESS, ChannelNumber);
  if (ChannelNumber < 0 || ChannelNumber > 125) {
    ChannelNumber = 108;
    EEPROM.put(EEPROM_ADDRESS, ChannelNumber);
  }

  Serial.print("EEPROM channel=");
  Serial.println(ChannelNumber);

  // Check Startup mode
  if (digitalRead(BUTTON_PIN) == HIGH) {
    Serial.println("Mode Setup");
    Serial.println("Please enter the new Channel (0-125): ");

    while (!Serial.available()) {
    }

    int newChannel = Serial.parseInt();

    while (!(newChannel >= 0 && newChannel <= 125)) {
      Serial.println("Invalid input. Please enter a valid channel (0-125): ");

      while (!Serial.available()) {
      }

      newChannel = Serial.parseInt();
    }

    if (newChannel != ChannelNumber) {
      Serial.print("Default Channel set to: ");
      Serial.println(newChannel);
      EEPROM.put(EEPROM_ADDRESS, newChannel);
      ChannelNumber = newChannel;
    }

    Serial.println("Setup complete. Please release the button to continue.");

    while (digitalRead(BUTTON_PIN) == HIGH) {
      delay(100);
    }
  }

  Serial.println("Starting radio...");

  while (!radio.begin()) {
    Serial.println("Radio non detectee, retry...");
    delay(500);
  }

  EEPROM.get(EEPROM_ADDRESS, ChannelNumber);

  radio.setPALevel(RF24_PA_MAX);
  radio.setPayloadSize(sizeof(msg));
  radio.setChannel(ChannelNumber);
  radio.setDataRate(RF24_1MBPS);
  radio.openWritingPipe(address);
  radio.stopListening();

  Serial.println("Radio OK");
  Serial.println("Transmitter ready");
}

void printDebugStatus(bool sent) {
  if (millis() - lastDebugPrint >= DEBUG_INTERVAL) {
    lastDebugPrint = millis();

    Serial.print("D2 bouton=");
    Serial.print(digitalRead(BUTTON_PIN) == HIGH ? "HIGH" : "LOW");

    Serial.print(" | msg=");
    Serial.print(msg ? "ALARM TRUE" : "ALARM FALSE");

    Serial.print(" | radio.write=");
    Serial.print(sent ? "OK" : "ECHEC");

    Serial.print(" | packets=");
    Serial.print(packetCount);

    Serial.print(" | channel=");
    Serial.println(ChannelNumber);
  }
}

void loop() {
  msg = digitalRead(BUTTON_PIN) == HIGH;

  bool sent = radio.write(&msg, sizeof(msg));
  packetCount++;

  printDebugStatus(sent);

  delay(period);
}

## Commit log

2026-09-16 Replace transmitter image with button image in README
2026-09-16 Add section for Receiver assembly instructions
2026-09-16 Update README with Receiver assembly details
    Add section for Receiver assembly and relays in README.
2026-09-17 Refactor testing and troubleshooting sections in README
    Removed redundant instructions for testing with LED and robot. Streamlined troubleshooting section for clarity.
2026-09-22 Update image source for Arduino card in README
2026-09-22 Update CAD
    [MonReceiver.FCStd, MonReceiverTop.FCStd, MonTransmitter.FCStd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]
2026-09-22 Fix heading for relay circuit description
    Corrected heading format for clarity.
2026-09-23 Update LED state descriptions in README
    Added descriptions for yellow LED states in the README.
2026-09-23 Adjust LED circuit image width in README
    Reduced the width of the LED circuit image in the README.
2026-10-02 changement cad files et photo
    [Transmitter (copy).FCStd, Transmitter-Corps.stl, Transmitter.FCStd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]
